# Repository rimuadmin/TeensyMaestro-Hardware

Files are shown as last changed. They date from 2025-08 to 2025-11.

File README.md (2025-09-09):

# TeensyMaestro Front Panel and PCB

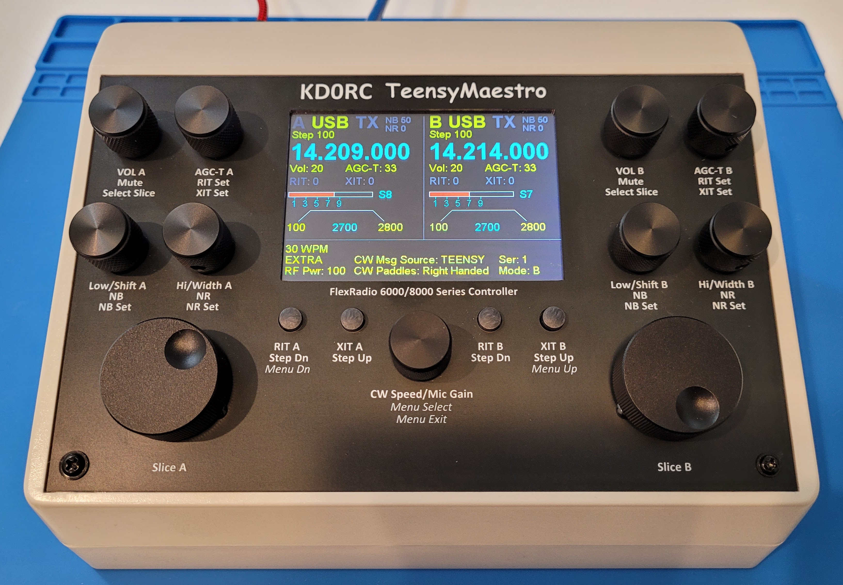
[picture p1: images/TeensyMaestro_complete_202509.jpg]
Assembled TeensyMaestro


### What Is TeensyMaestro?
The TeensyMaestro is a custom-built hardware controller first designed by Len (KD0RC) to interface with FlexRadio transceivers - specifically models in the 6000 and 8000 series. It performs some, but not all, of the common functions that the SmartSDR app or the Flex Maestro perform. The name TeensyMaestro comes from its core component: the Teensy 4.1 microcontroller, which powers the device. Len's initial version was built using point-to-point wiring which presented a challenge for builders. Len (KD0RC) and Simon (NV0E) have created a PCB and matching front panel that simplifies the build process. 

### What Is This Project?
This repository describes the version 2 PCB and Front Panel hardware. The intent of this PCB is to simplify the build process, make it easier to produce a polished final product, and replace some components with less expensive alternatives. It has detailed instructions that describe how to order parts, build and assemble a TeensyMaestro using the version 2 hardware.

The documentation for building the PCB and Front panel is here: 

[TeensyMaestro Hardware Wiki](https://github.com/rimuadmin/TeensyMaestro-Hardware/wiki)

Len's firmware that supports all versions is available here:

[TeensyMaestro for Flex 6000 Radios](https://github.com/KD0RC/Teensy-Maestro-for-Flex-6000-radios)

Len's GitHub page has a detailed user manual that explains how to operate the TeensyMaestro and build instructions for version 1.

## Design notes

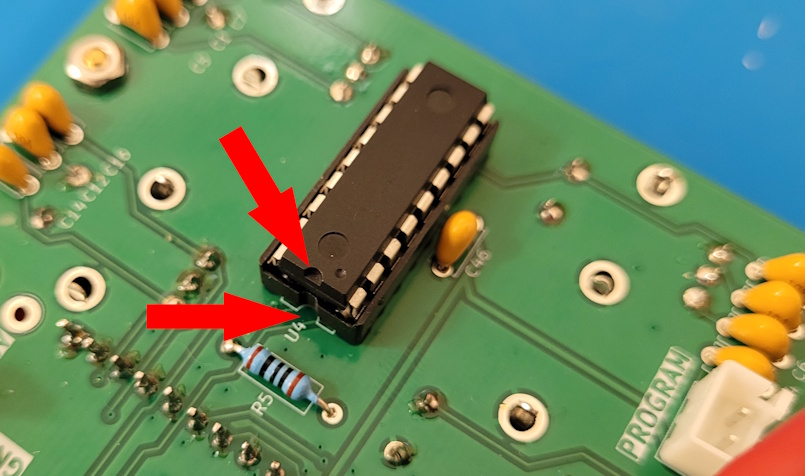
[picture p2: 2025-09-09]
images/mcp23008_right_position.jpg

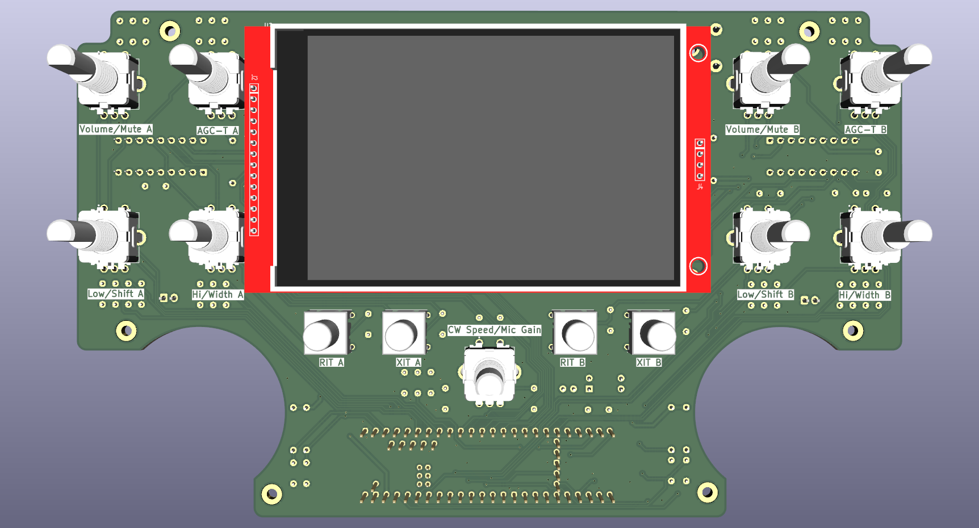
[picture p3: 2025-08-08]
images/front_side_2025-08-06.png

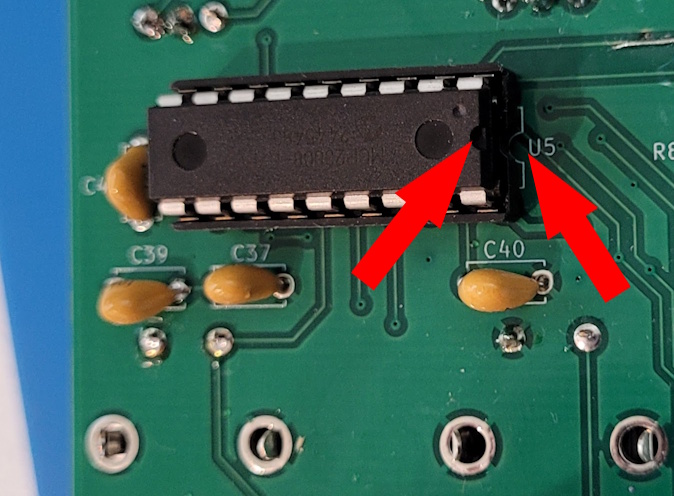
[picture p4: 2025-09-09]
images/mcp23008_left_position.jpg

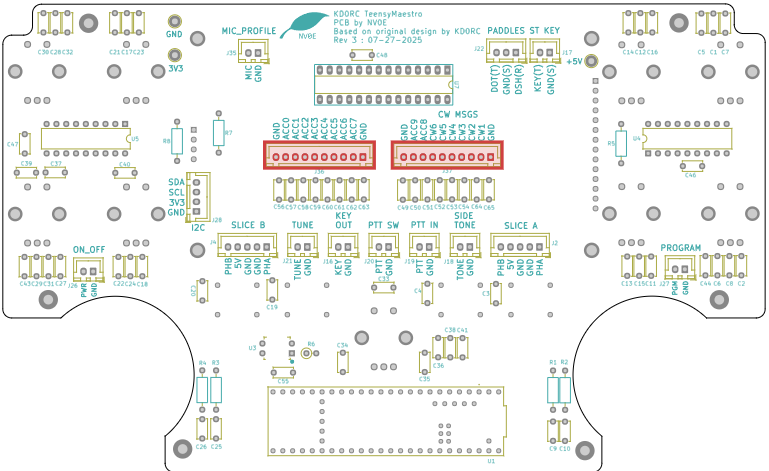
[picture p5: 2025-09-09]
images/XH_10-pin_connector.png

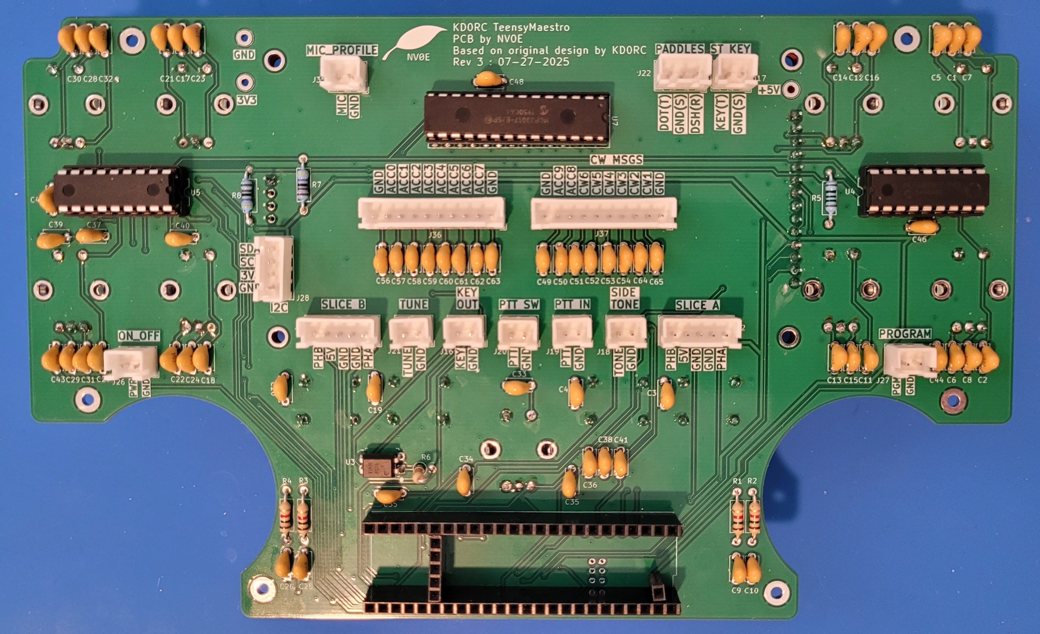
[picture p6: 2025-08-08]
images/TeensyMaestro_pcb_rear_20250806.jpg

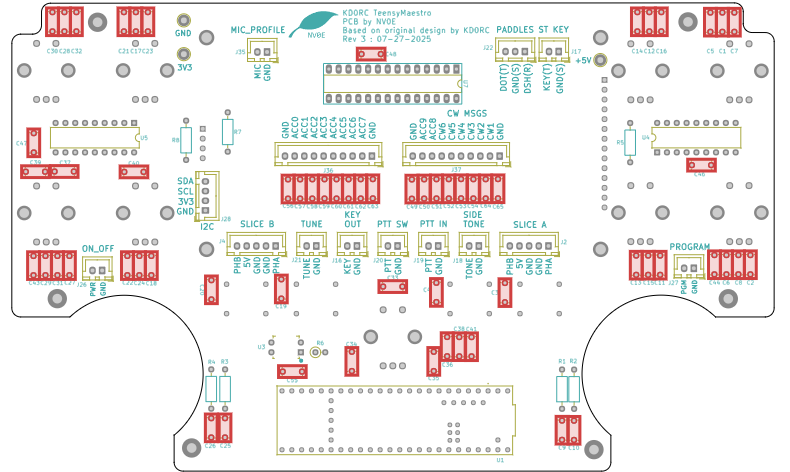
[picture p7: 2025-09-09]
images/tm_capacitor_positions.png

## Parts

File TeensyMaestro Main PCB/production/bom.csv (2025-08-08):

Designator | Footprint | Quantity | Value | LCSC Part #
C1, C10, C11, C12, C13, C14, C15, C16, C17, C18, C19, C2, C20, C21, C22, C23, C24, C25, C26, C27, C28, C29, C3, C30, C31, C32, C33, C34, C35, C36, C37, C38, C39, C4, C40, C41, C43, C44, C46, C47, C48, C49, C5, C50, C51, C52, C53, C54, C55, C56, C57, C58, C59, C6, C60, C61, C62, C63, C64, C65, C7, C8, C9 | C_Disc_D5.0mm_W2.5mm_P5.00mm | 63 | 100nF
H1, H2, H3, H4, H5, H6 | MountingHole_2.5mm_Pad | 6 | MountingHole
J16, J17, J18, J19, J20, J21, J26, J27, J35 | JST_XH_B2B-XH-A_1x02_P2.50mm_Vertical | 9 | B2B-XH-A_LF__SN_ | B2B-XH-A(LF)(SN)
J2, J4 | JST_XH_B5B-XH-A_1x05_P2.50mm_Vertical | 2 | B5B-XH-A_LF__SN_ | B5B-XH-A(LF)(SN)
J22 | JST_XH_B3B-XH-A_1x03_P2.50mm_Vertical | 1 | B3B-XH-A_LF__SN_ | B3B-XH-A(LF)(SN)
J28 | JST_XH_B4B-XH-A_1x04_P2.50mm_Vertical | 1 | B4B-PH-K-S_LF__SN_ | B4B-PH-K-S(LF)(SN)
J36, J37 | JST_XH_B10B-XH-A_1x10_P2.50mm_Vertical | 2 | Conn_01x10
R1, R2, R3, R4 | R_Axial_DIN0207_L6.3mm_D2.5mm_P10.16mm_Horizontal | 4 | 1K
R5 | R_Axial_DIN0207_L6.3mm_D2.5mm_P10.16mm_Horizontal | 1 | 100
R6 | R_Axial_DIN0207_L6.3mm_D2.5mm_P2.54mm_Vertical | 1 | 1K
R7, R8 | R_Axial_DIN0207_L6.3mm_D2.5mm_P10.16mm_Horizontal | 2 | 4K7
S1, S2, S3, S4 | 3ETH9120 | 4 | 1825910-6 | 1825910-6
SW10 | PEC11L4115FS0020_NR | 1 | AGC-T/RIT_Sel A
SW11 | PEC11L4115FS0020 | 1 | CW_Mic/Menu Sel
SW2 | PEC11L4115FS0020_NR | 1 | RotaryEncoder_Switch_MP
SW3 | PEC11L4115FS0020_NR | 1 | LowShift/NB A
SW4 | PEC11L4115FS0020_VNR | 1 | HighWidth/NR A
SW5 | PEC11L4115FS0020_VNR | 1 | AGC-T/RIT_Sel A
SW7 | PEC11L4115FS0020_VNR | 1 | Vol/Mute B
SW8 | PEC11L4115FS0020_VNR | 1 | LowShift/NB B
SW9 | PEC11L4115FS0020_NR | 1 | HighWidth/NR B
TP1 | TestPoint_Loop_D2.54mm_Drill1.5mm_Beaded | 1 | 5V
TP2 | TestPoint_Loop_D2.54mm_Drill1.5mm_Beaded | 1 | 3V3
TP3 | TestPoint_Loop_D2.54mm_Drill1.5mm_Beaded | 1 | GND
U1 | MODULE_DEV-16771 | 1 | DEV-16771
U2 | MSP4021-ST7796S-TM | 1 | MSP4021-ST7796S
U3 | DIP-4_W7.62mm | 1 | LTV-817 | LTV-817
U4, U5 | DIP-18_W7.62mm | 2 | MCP23008-xP
U7 | DIP-28_W7.62mm_Socket_LongPads | 1 | MCP23017-E_SP | MCP23017-E/SP

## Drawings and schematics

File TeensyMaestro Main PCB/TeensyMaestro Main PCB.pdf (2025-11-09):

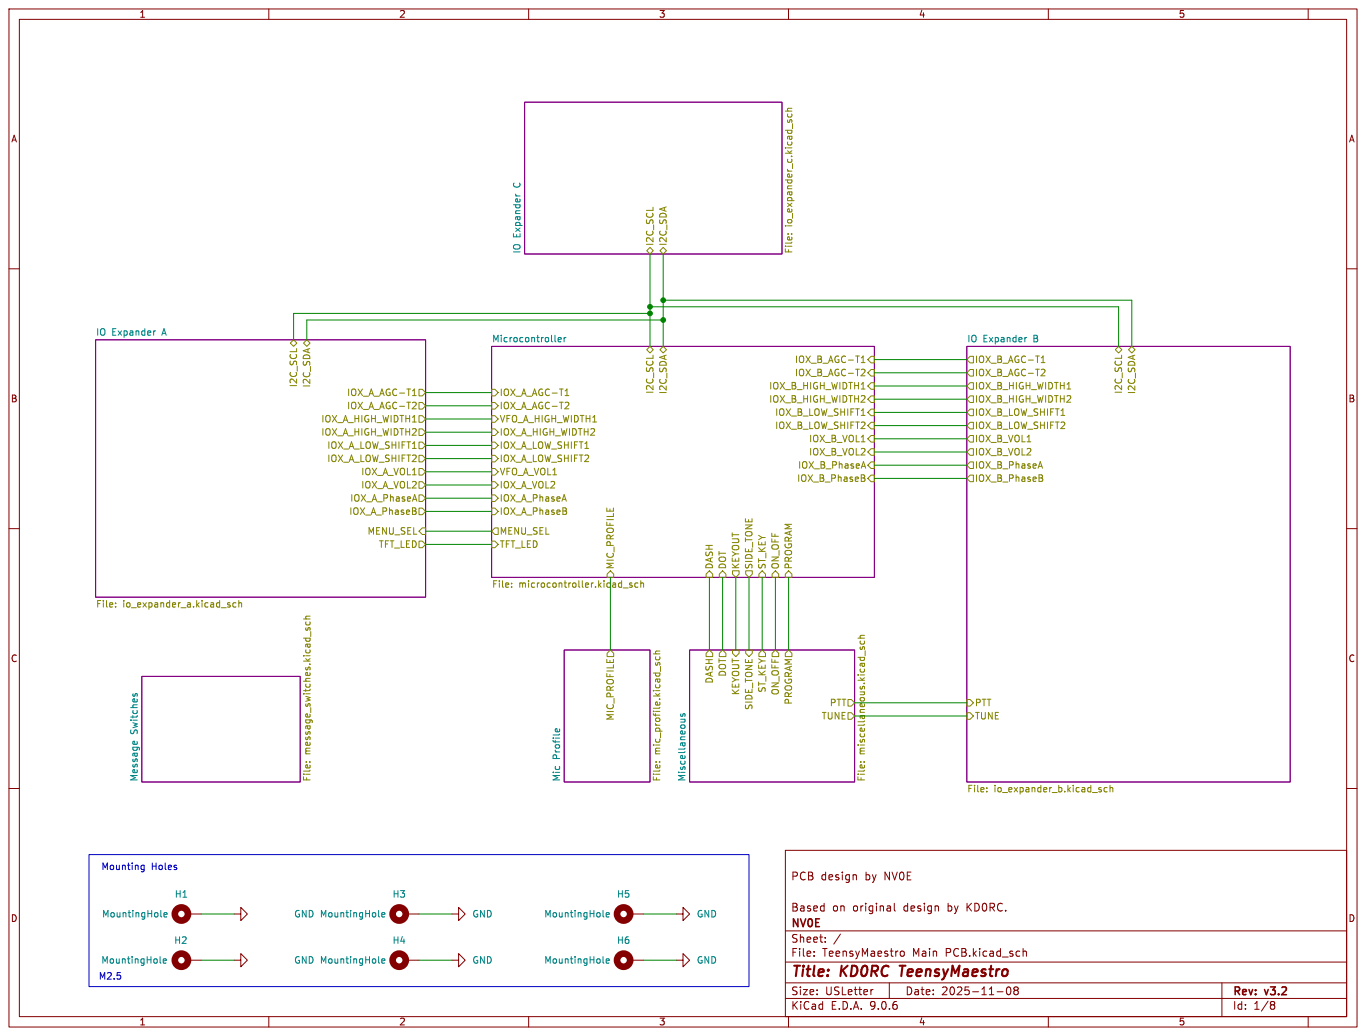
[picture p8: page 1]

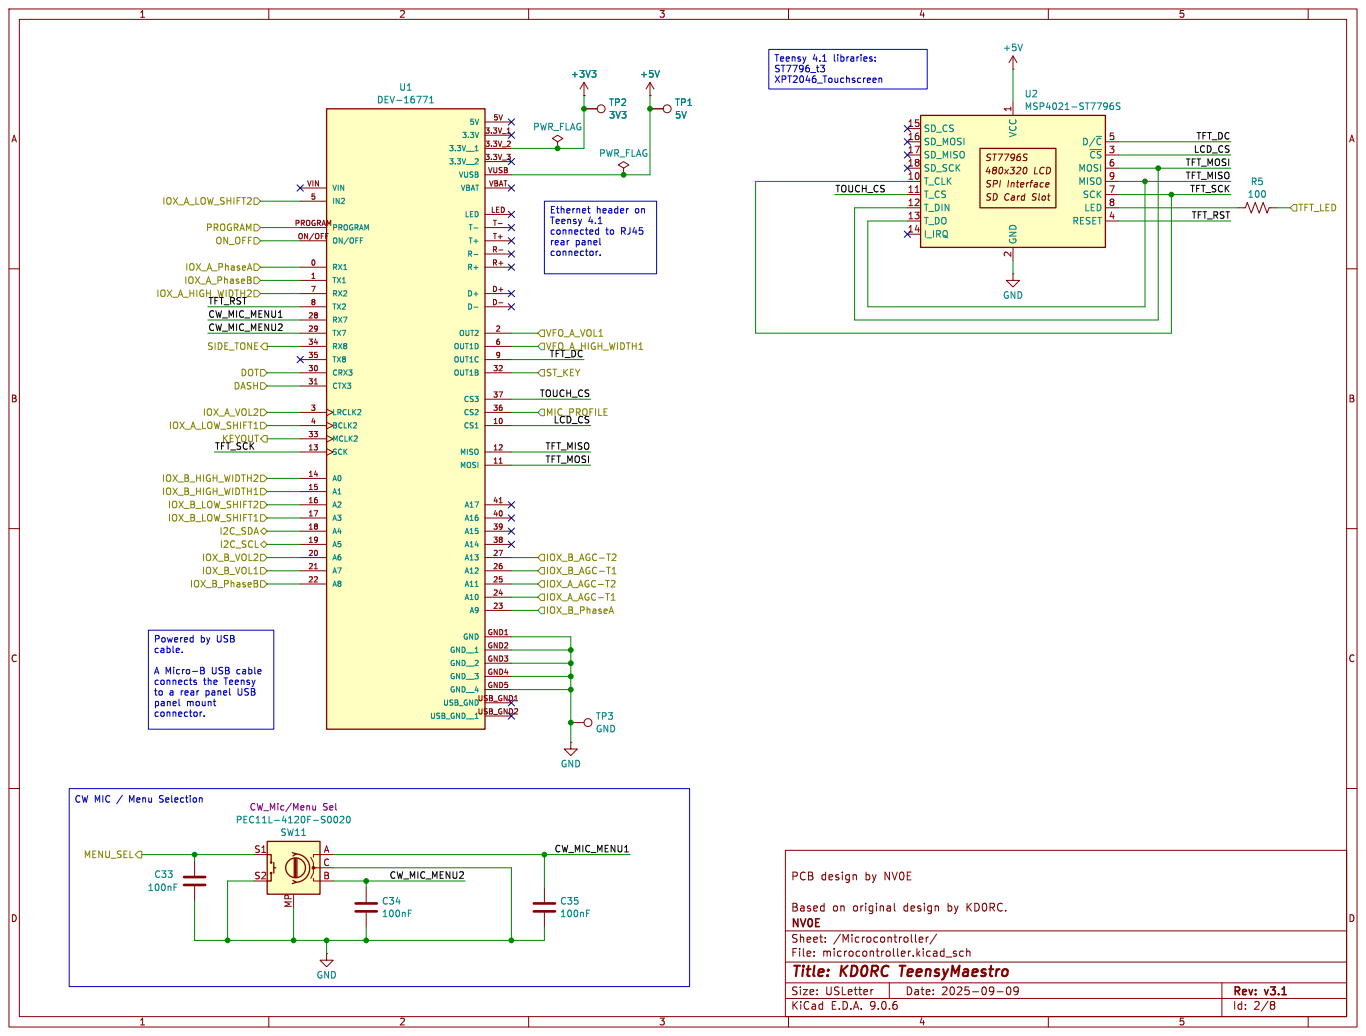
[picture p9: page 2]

Teensy 4.1 libraries: ST7796_t3 XPT2046_Touchscreen Powered by USB

2 D/~{C}5 ~{CS}3 MOSI 6 MISO 9 SCK 7

100 MIC_PROFILE
Ethernet header on Teensy 4.1

rear panel connector. CW MIC / Menu Selection

to a rear panel USB
panel mount connector.

File: microcontroller.kicad_sch Sheet: /Microcontroller/ NV0E

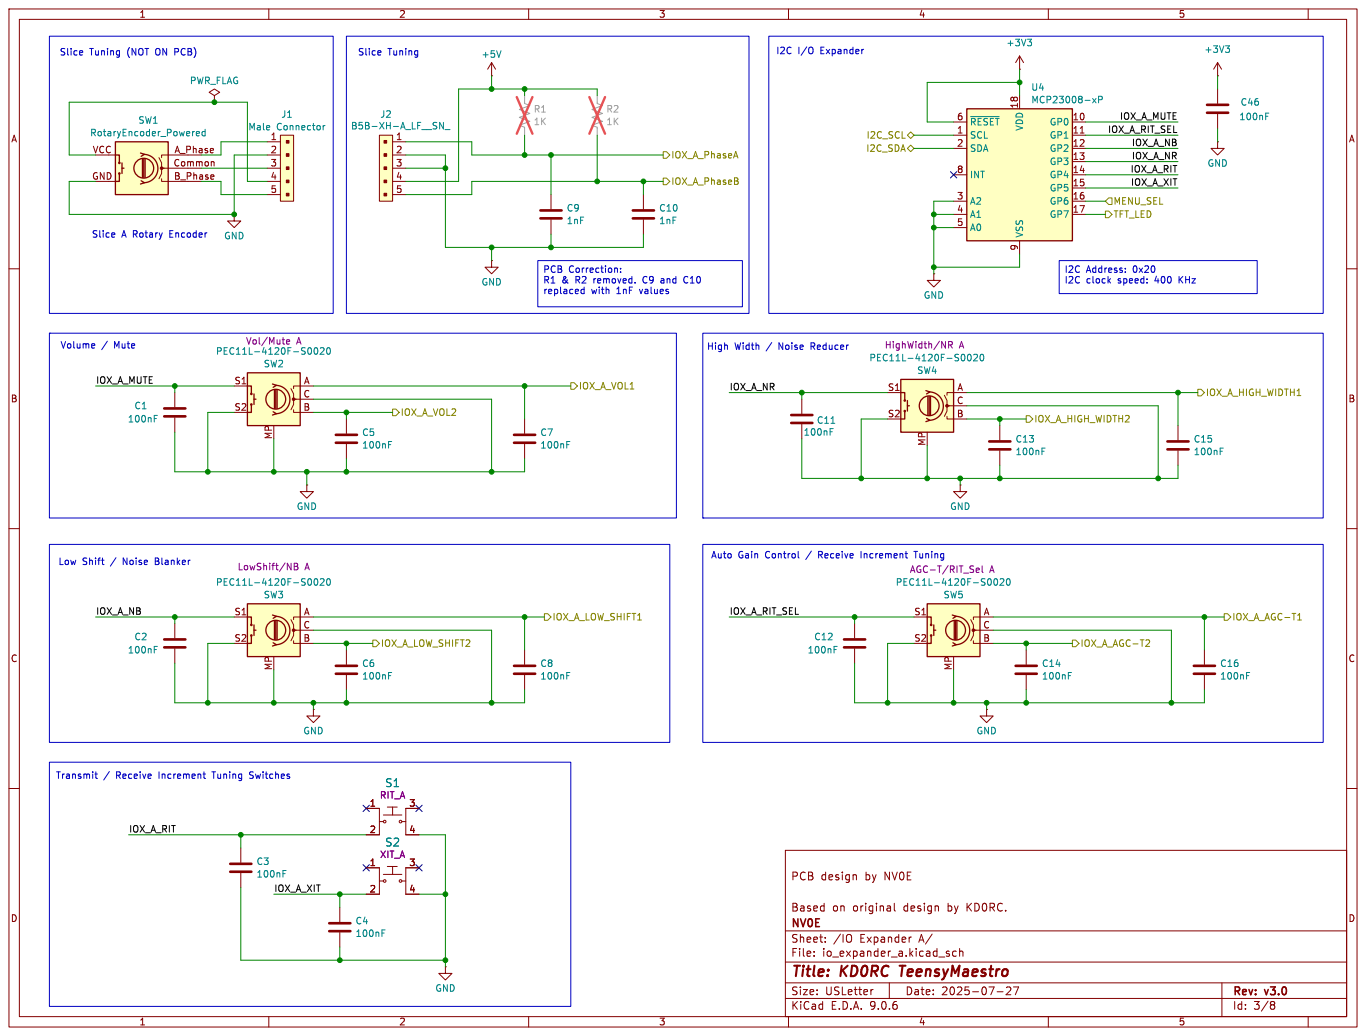
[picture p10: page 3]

I2C clock speed: 400 KHz PCB Correction: R1 & R2 removed. C9 and C10

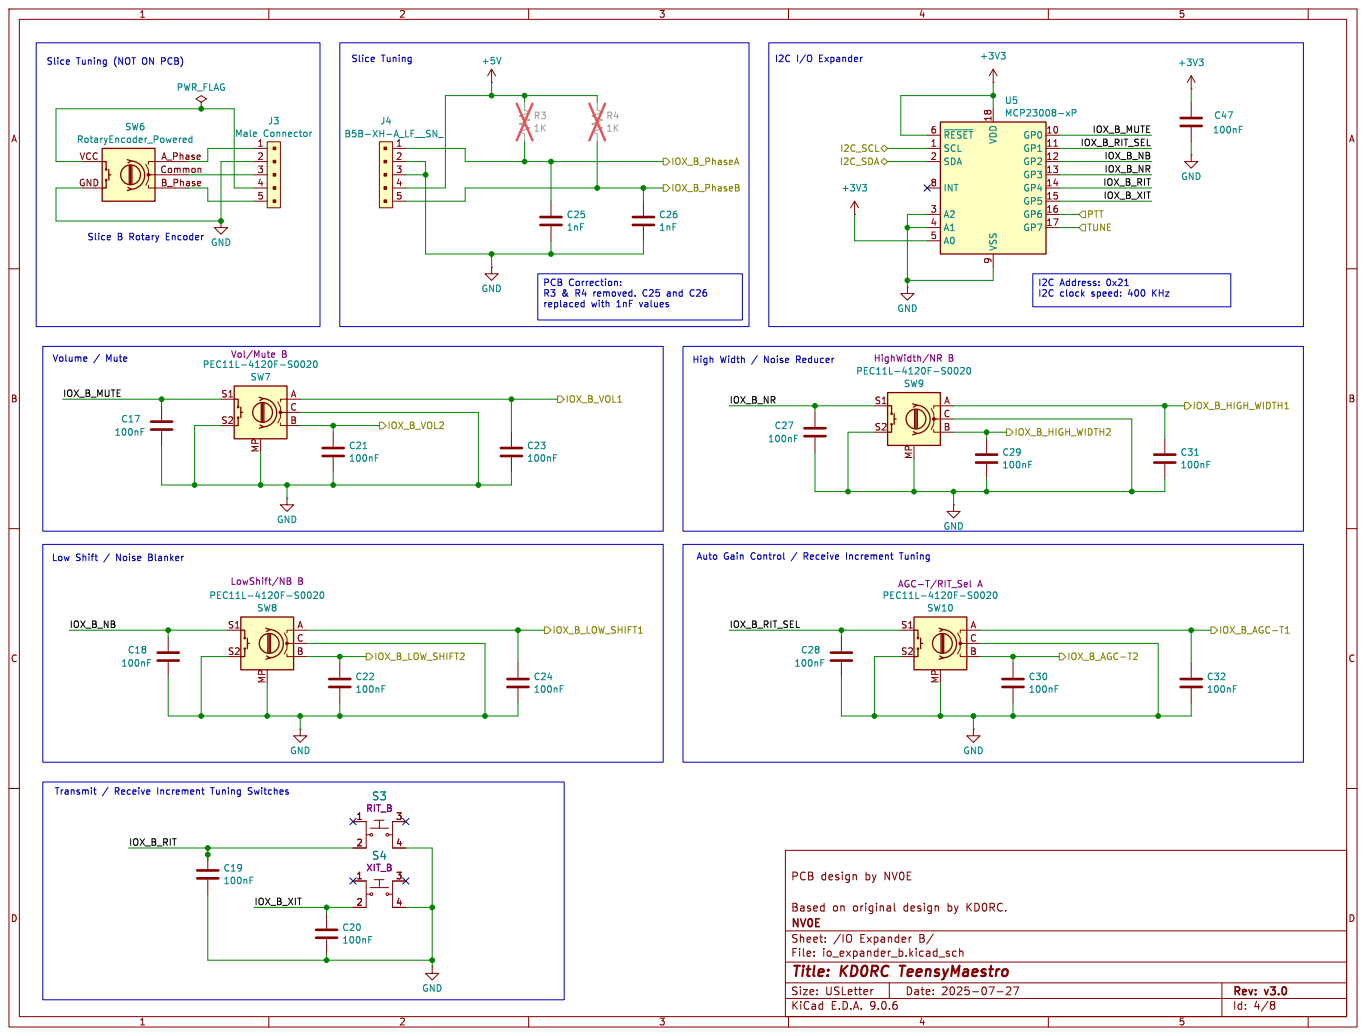
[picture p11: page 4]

I2C clock speed: 400 KHz PCB Correction: R3 & R4 removed. C25 and C26

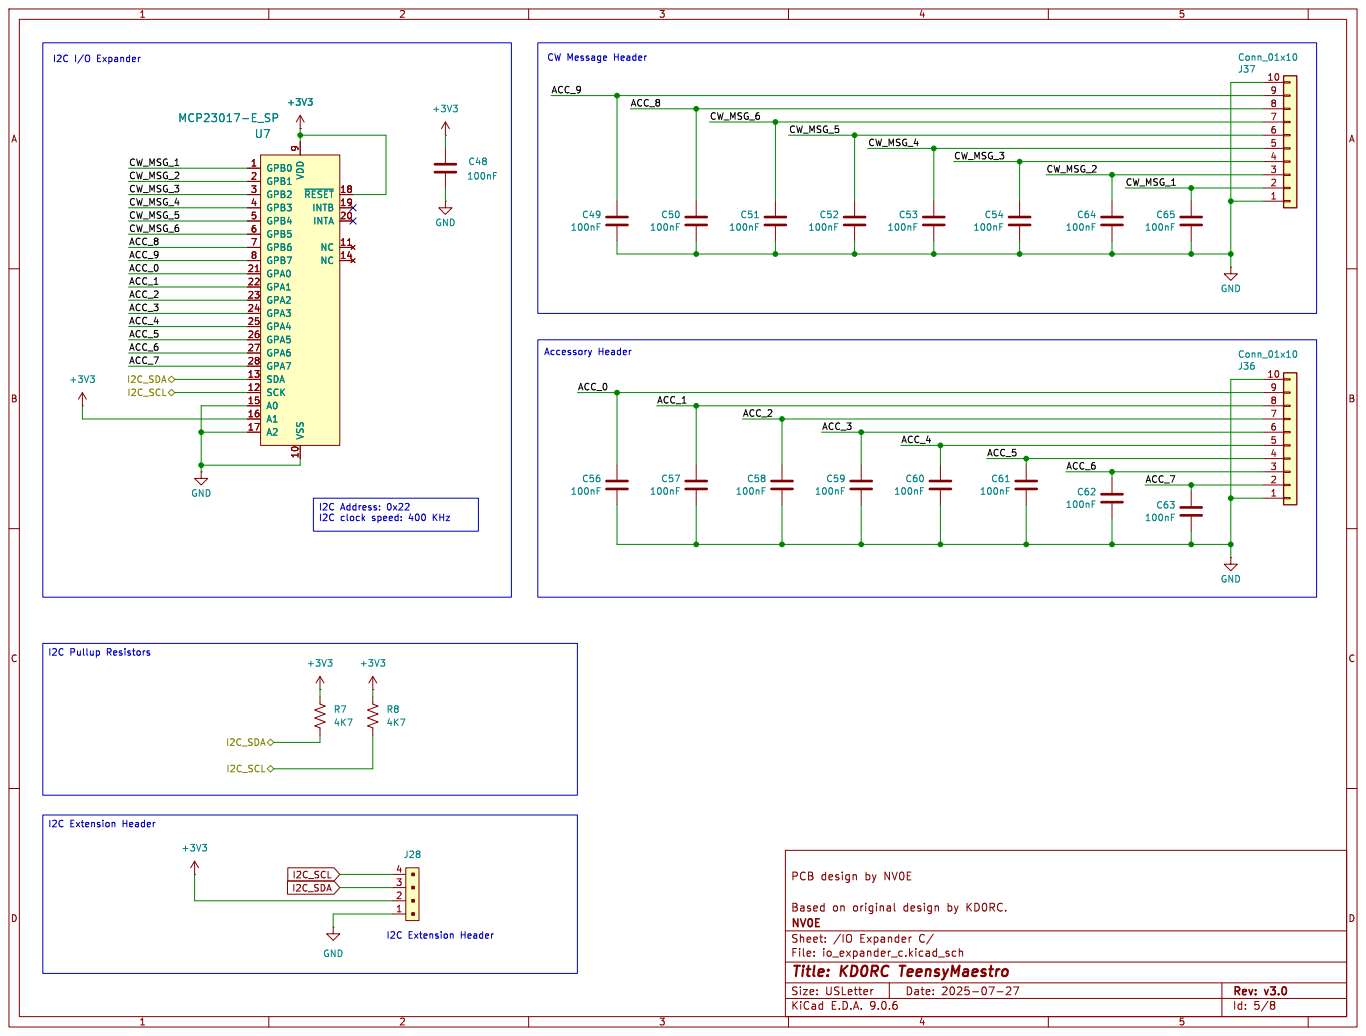
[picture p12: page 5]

Accessory Header CW Message Header U7 MCP23017-E_SP

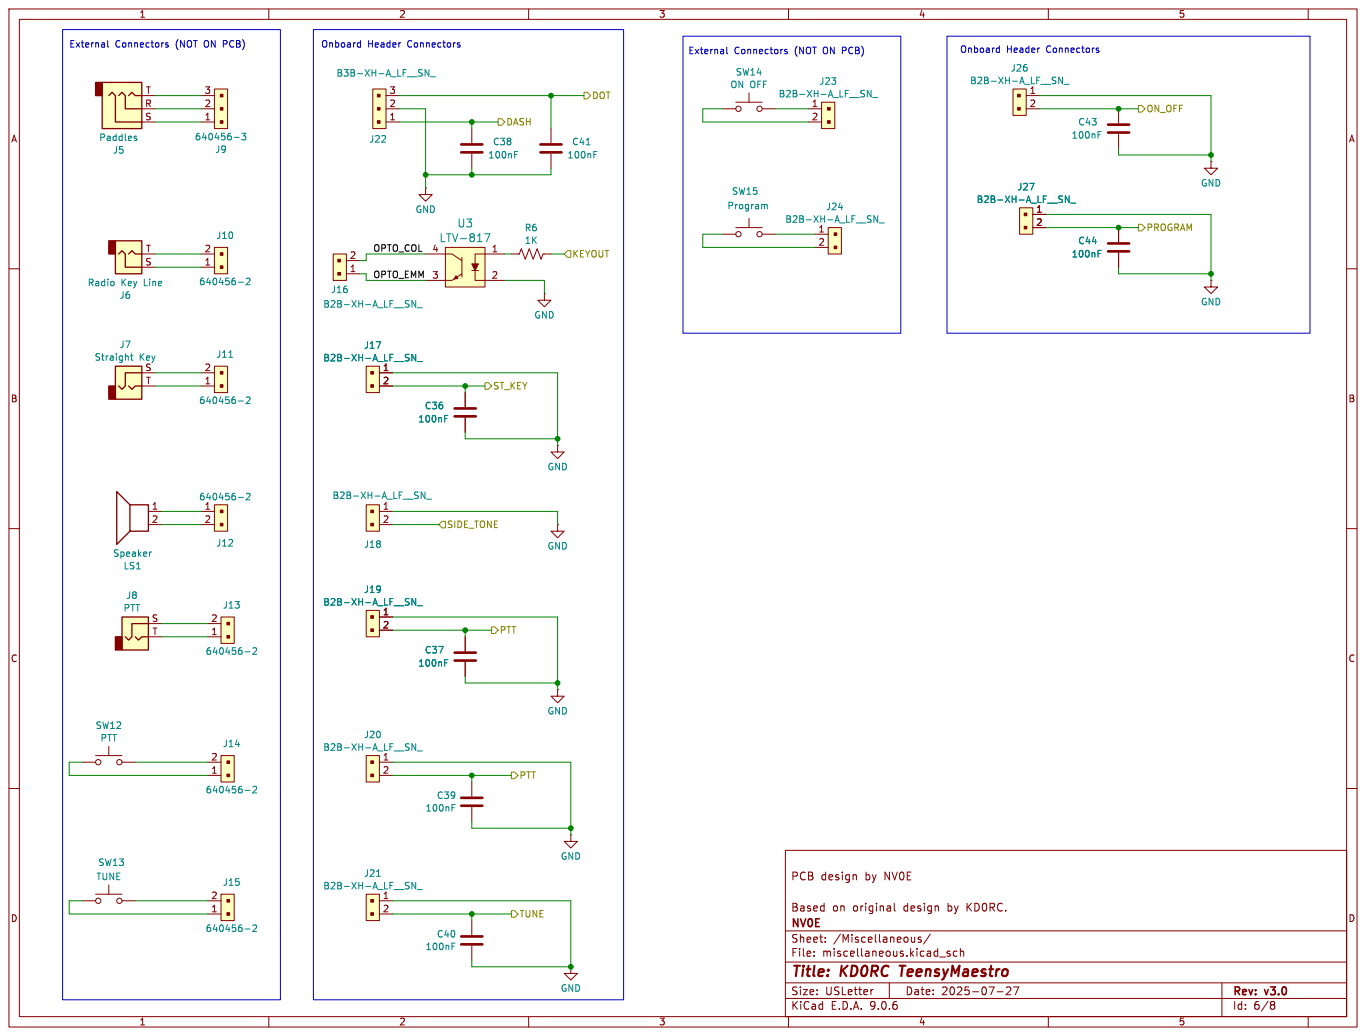
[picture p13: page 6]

J23 B2B-XH-A_LF__SN_ SW14 ON OFF SW15 Program

File: miscellaneous.kicad_sch Sheet: /Miscellaneous/ NV0E

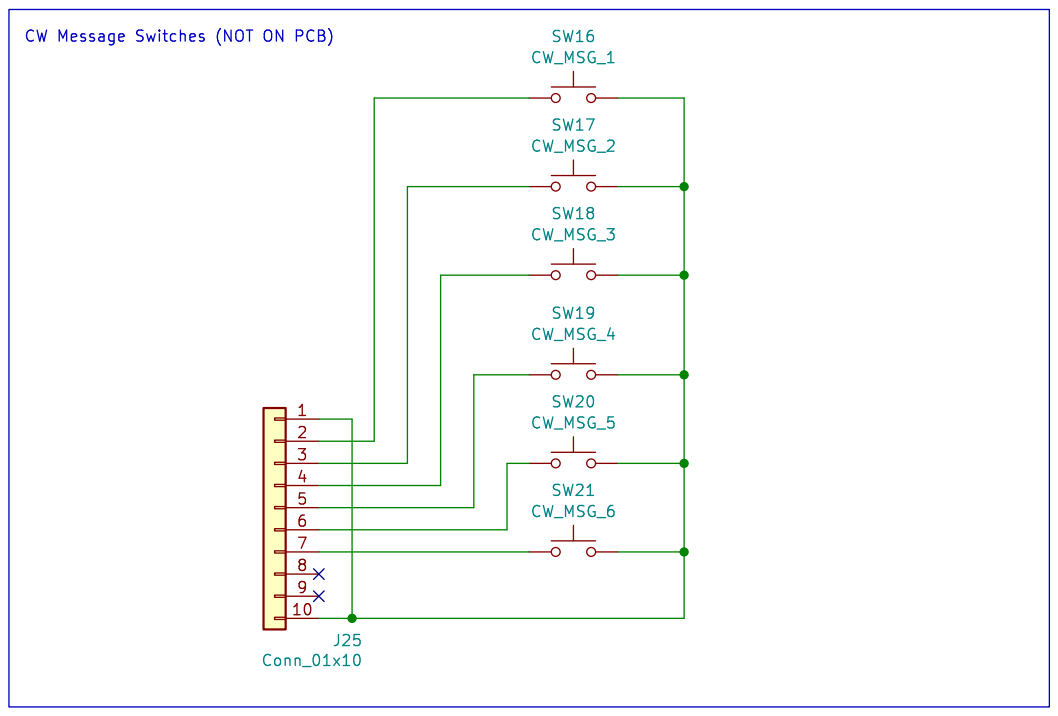
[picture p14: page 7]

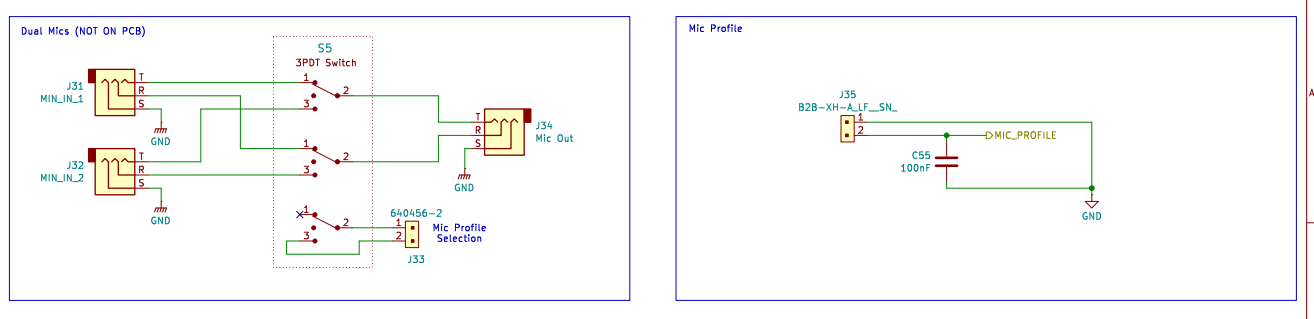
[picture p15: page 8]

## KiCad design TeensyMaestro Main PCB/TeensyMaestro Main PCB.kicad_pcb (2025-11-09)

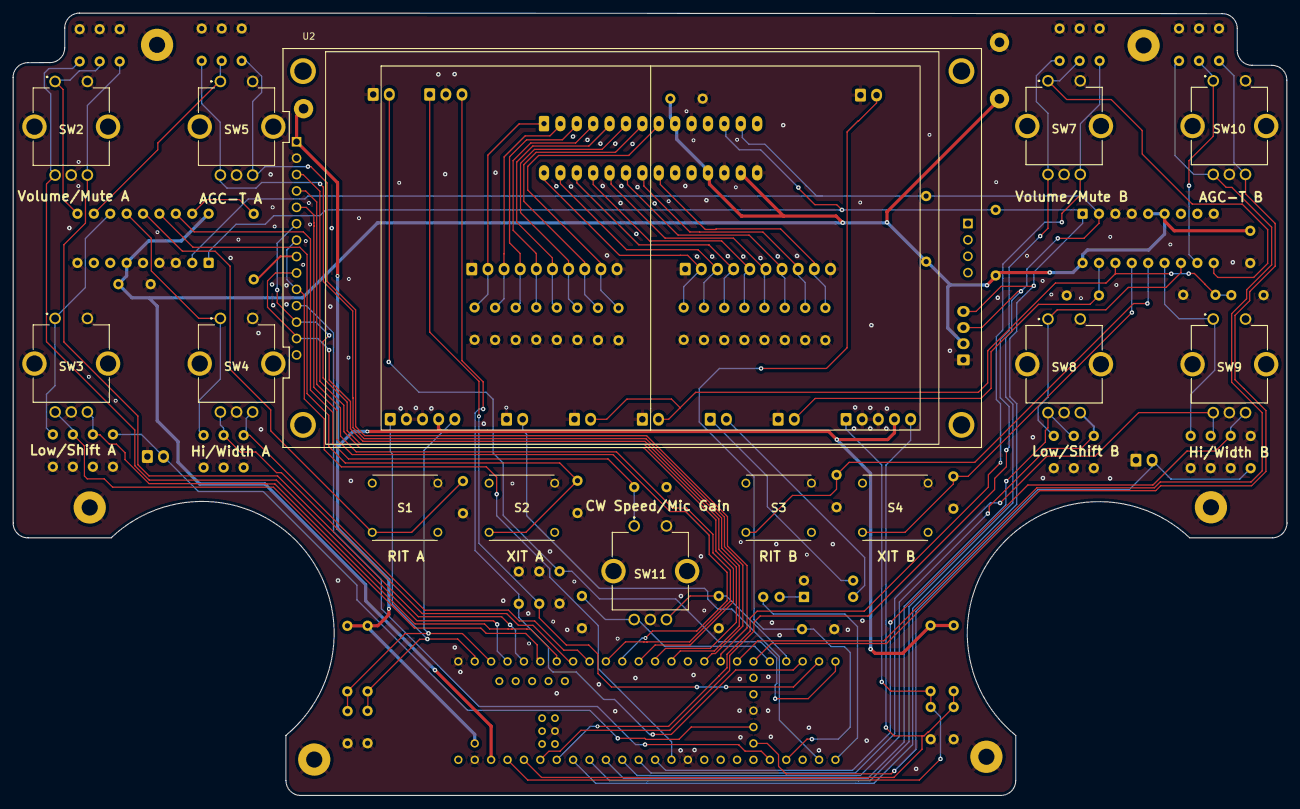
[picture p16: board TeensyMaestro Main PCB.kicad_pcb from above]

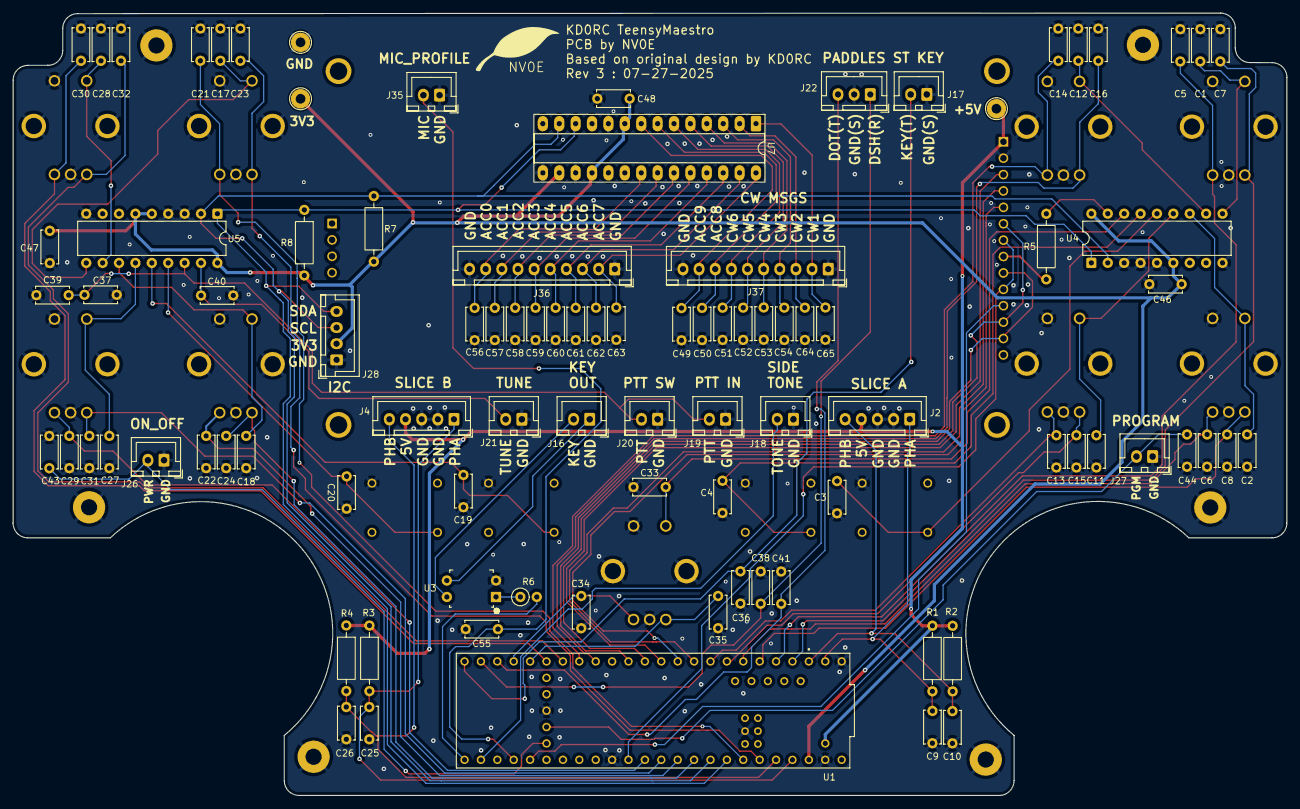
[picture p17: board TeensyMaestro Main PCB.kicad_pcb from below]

Board: 2 copper layers, 197.3 x 121.2 mm, 114 parts (94 on the bottom side), 78 nets.

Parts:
C1, C2, C3, C4, C5, C6, C7, C8, C11, C12, C13, C14, C15, C16, C17, C18, C19, C20, C21, C22, C23, C24, C27, C28, C29, C30, C31, C32, C33, C34, C35, C36, C37, C38, C39, C40, C41, C43, C44, C46, C47, C48, C49, C50, C51, C52, C53, C54, C55, C56, C57, C58, C59, C60, C61, C62, C63, C64, C65: 100nF; C_Disc_D5.0mm_W2.5mm_P5.00mm
C9, C10, C25, C26: 1nF; C_Disc_D5.0mm_W2.5mm_P5.00mm
H1, H2, H3, H4, H5, H6: MountingHole; MountingHole_2.5mm_Pad
J2, J4: B5B-XH-A_LF__SN_; JST_XH_B5B-XH-A_1x05_P2.50mm_Vertical
J16, J17, J18, J19, J20, J21, J26, J27, J35: B2B-XH-A_LF__SN_; JST_XH_B2B-XH-A_1x02_P2.50mm_Vertical
J22: B3B-XH-A_LF__SN_; JST_XH_B3B-XH-A_1x03_P2.50mm_Vertical
J28: B4B-PH-K-S_LF__SN_; JST_XH_B4B-XH-A_1x04_P2.50mm_Vertical
J36, J37: Conn_01x10; JST_XH_B10B-XH-A_1x10_P2.50mm_Vertical
R1, R2, R3, R4: 1K; R_Axial_DIN0207_L6.3mm_D2.5mm_P10.16mm_Horizontal
R5: 100; R_Axial_DIN0207_L6.3mm_D2.5mm_P10.16mm_Horizontal
R6: 1K; R_Axial_DIN0207_L6.3mm_D2.5mm_P2.54mm_Vertical
R7, R8: 4K7; R_Axial_DIN0207_L6.3mm_D2.5mm_P10.16mm_Horizontal
S1, S2, S3, S4: 1825910-6; 3ETH9120
SW2, SW3, SW9, SW10: PEC11L-4120F-S0020; PEC11L4115FS0020_NR
SW4, SW5, SW7, SW8: PEC11L-4120F-S0020; PEC11L4115FS0020_VNR
SW11: PEC11L-4120F-S0020; PEC11L4115FS0020
TP1: 5V; TestPoint_Loop_D2.54mm_Drill1.5mm_Beaded
TP2: 3V3; TestPoint_Loop_D2.54mm_Drill1.5mm_Beaded
TP3: GND; TestPoint_Loop_D2.54mm_Drill1.5mm_Beaded
U1: DEV-16771; MODULE_DEV-16771
U2: MSP4021-ST7796S; MSP4021-ST7796S-TM
U3: LTV-817; DIP-4_W7.62mm
U4, U5: MCP23008-xP; DIP-18_W7.62mm
U7: MCP23017-E_SP; DIP-28_W7.62mm_Socket_LongPads

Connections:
+3V3: C46.1, C47.1, C48.1, J28.2, R7.2, R8.2, TP2.1, U1.3.3V_2 (3.3V__1), U4.6 (~RESET), U4.18 (VDD), U5.5 (A0), U5.6 (~RESET), U5.18 (VDD), U7.9 (VDD), U7.16 (A1), U7.18 (~RESET)
+5V: J2.4, J4.4, R1.1, R2.1, R3.1, R4.1, TP1.1, U1.VUSB, U2.1 (VCC)
/IO Expander A/IOX_A_AGC-T1: C16.1, SW5.A, U1.24 (A10)
/IO Expander A/IOX_A_AGC-T2: C14.1, SW5.B, U1.25 (A11)
/IO Expander A/IOX_A_HIGH_WIDTH1: C15.1, SW4.A, U1.6 (OUT1D)
/IO Expander A/IOX_A_HIGH_WIDTH2: C13.1, SW4.B, U1.7 (RX2)
/IO Expander A/IOX_A_LOW_SHIFT1: C8.1, SW3.A, U1.4 (BCLK2)
/IO Expander A/IOX_A_LOW_SHIFT2: C6.1, SW3.B, U1.5 (IN2)
/IO Expander A/IOX_A_MUTE: C1.1, SW2.S1, U4.10 (GP0)
/IO Expander A/IOX_A_NB: C2.1, SW3.S1, U4.12 (GP2)
/IO Expander A/IOX_A_NR: C11.1, SW4.S1, U4.13 (GP3)
/IO Expander A/IOX_A_PhaseA: C9.1, J2.1, R1.2, U1.0 (RX1)
/IO Expander A/IOX_A_PhaseB: C10.1, J2.5, R2.2, U1.1 (TX1)
/IO Expander A/IOX_A_RIT: C3.1, S1.2, U4.14 (GP4)
/IO Expander A/IOX_A_RIT_SEL: C12.1, SW5.S1, U4.11 (GP1)
/IO Expander A/IOX_A_VOL1: C7.1, SW2.A, U1.2 (OUT2)
/IO Expander A/IOX_A_VOL2: C5.1, SW2.B, U1.3 (LRCLK2)
/IO Expander A/IOX_A_XIT: C4.1, S2.2, U4.15 (GP5)
/IO Expander A/MENU_SEL: C33.1, SW11.S1, U4.16 (GP6)
/IO Expander A/TFT_LED: R5.2, U4.17 (GP7)
/IO Expander B/IOX_B_AGC-T1: C32.1, SW10.A, U1.26 (A12)
/IO Expander B/IOX_B_AGC-T2: C30.1, SW10.B, U1.27 (A13)
/IO Expander B/IOX_B_HIGH_WIDTH1: C31.1, SW9.A, U1.15 (A1)
/IO Expander B/IOX_B_HIGH_WIDTH2: C29.1, SW9.B, U1.14 (A0)
/IO Expander B/IOX_B_LOW_SHIFT1: C24.1, SW8.A, U1.17 (A3)
/IO Expander B/IOX_B_LOW_SHIFT2: C22.1, SW8.B, U1.16 (A2)
/IO Expander B/IOX_B_MUTE: C17.1, SW7.S1, U5.10 (GP0)
/IO Expander B/IOX_B_NB: C18.1, SW8.S1, U5.12 (GP2)
/IO Expander B/IOX_B_NR: C27.1, SW9.S1, U5.13 (GP3)
/IO Expander B/IOX_B_PhaseA: C25.1, J4.1, R3.2, U1.23 (A9)
/IO Expander B/IOX_B_PhaseB: C26.1, J4.5, R4.2, U1.22 (A8)
/IO Expander B/IOX_B_RIT: C19.1, S3.2, U5.14 (GP4)
/IO Expander B/IOX_B_RIT_SEL: C28.1, SW10.S1, U5.11 (GP1)
/IO Expander B/IOX_B_VOL1: C23.1, SW7.A, U1.21 (A7)
/IO Expander B/IOX_B_VOL2: C21.1, SW7.B, U1.20 (A6)
/IO Expander B/IOX_B_XIT: C20.1, S4.2, U5.15 (GP5)
/IO Expander B/PTT: C37.1, C39.1, J19.2, J20.2, U5.16 (GP6)
/IO Expander B/TUNE: C40.1, J21.2, U5.17 (GP7)
/IO Expander C/ACC_0: C56.1, J36.9, U7.21 (GPA0)
/IO Expander C/ACC_1: C57.1, J36.8, U7.22 (GPA1)
/IO Expander C/ACC_2: C58.1, J36.7, U7.23 (GPA2)
/IO Expander C/ACC_3: C59.1, J36.6, U7.24 (GPA3)
/IO Expander C/ACC_4: C60.1, J36.5, U7.25 (GPA4)
/IO Expander C/ACC_5: C61.1, J36.4, U7.26 (GPA5)
/IO Expander C/ACC_6: C62.1, J36.3, U7.27 (GPA6)
/IO Expander C/ACC_7: C63.1, J36.2, U7.28 (GPA7)
/IO Expander C/ACC_8: C50.1, J37.8, U7.7 (GPB6)
/IO Expander C/ACC_9: C49.1, J37.9, U7.8 (GPB7)
/IO Expander C/CW_MSG_1: C65.1, J37.2, U7.1 (GPB0)
/IO Expander C/CW_MSG_2: C64.1, J37.3, U7.2 (GPB1)
/IO Expander C/CW_MSG_3: C54.1, J37.4, U7.3 (GPB2)
/IO Expander C/CW_MSG_4: C53.1, J37.5, U7.4 (GPB3)
/IO Expander C/CW_MSG_5: C52.1, J37.6, U7.5 (GPB4)
/IO Expander C/CW_MSG_6: C51.1, J37.7, U7.6 (GPB5)
/Mic Profile/MIC_PROFILE: C55.1, J35.2, U1.36 (CS2)
/Microcontroller/CW_MIC_MENU1: C35.1, SW11.A, U1.28 (RX7)
/Microcontroller/CW_MIC_MENU2: C34.1, SW11.B, U1.29 (TX7)
/Microcontroller/DASH: C38.1, J22.1, U1.31 (CTX3)
/Microcontroller/DOT: C41.1, J22.3, U1.30 (CRX3)
/Microcontroller/KEYOUT: R6.2, U1.33 (MCLK2)
/Microcontroller/LCD_CS: U1.10 (CS1), U2.3 (~CS)
/Microcontroller/ON_OFF: C43.1, J26.2, U1.ON/OFF
/Microcontroller/PROGRAM: C44.1, J27.2, U1.PROGRAM
/Microcontroller/SIDE_TONE: J18.2, U1.34 (RX8)
/Microcontroller/ST_KEY: C36.1, J17.2, U1.32 (OUT1B)
/Microcontroller/TFT_DC: U1.9 (OUT1C), U2.5 (D/~C)
/Microcontroller/TFT_MISO: U1.12 (MISO), U2.9 (MISO), U2.13 (T_DO)
/Microcontroller/TFT_MOSI: U1.11 (MOSI), U2.6 (MOSI), U2.12 (T_DIN)
/Microcontroller/TFT_RST: U1.8 (TX2), U2.4 (RESET)
/Microcontroller/TFT_SCK: U1.13 (SCK), U2.7 (SCK), U2.10 (T_CLK)
/Microcontroller/TOUCH_CS: U1.37 (CS3), U2.11 (T_CS)
/Miscellaneous/OPTO_COL: J16.2, U3.4
/Miscellaneous/OPTO_EMM: J16.1, U3.3
GND: C1.2, C2.2, C3.2, C4.2, C5.2, C6.2, C7.2, C8.2, C9.2, C10.2, C11.2, C12.2, C13.2, C14.2, C15.2, C16.2, C17.2, C18.2, C19.2, C20.2, C21.2, C22.2, C23.2, C24.2, C25.2, C26.2, C27.2, C28.2, C29.2, C30.2, C31.2, C32.2, C33.2, C34.2, C35.2, C36.2, C37.2, C38.2, C39.2, C40.2, C41.2, C43.2, C44.2, C46.2, C47.2, C48.2, C49.2, C50.2, C51.2, C52.2, C53.2, C54.2, C55.2, C56.2, C57.2, C58.2, C59.2, C60.2, C61.2, C62.2, C63.2, C64.2, C65.2, H1.1, H2.1, H3.1, H4.1, H5.1, H6.1, J2.2, J2.3, J4.2, J4.3, J17.1, J18.1, J19.1, J20.1, J21.1, J22.2, J26.1, J27.1, J28.1, J35.1, J36.1, J36.10, J37.1, J37.10, S1.4, S2.4, S3.4, S4.4, SW2.C, SW2.MP, SW2.S2, SW3.C, SW3.MP, SW3.S2, SW4.C, SW4.MP, SW4.S2, SW5.C, SW5.MP, SW5.S2, SW7.C, SW7.MP, SW7.S2, SW8.C, SW8.MP, SW8.S2, SW9.C, SW9.MP, SW9.S2, SW10.C, SW10.MP, SW10.S2, SW11.C, SW11.MP, SW11.S2, TP3.1, U1.GND1 (GND), U1.GND2 (GND__1), U1.GND3 (GND__2), U1.GND4 (GND__3), U1.GND5 (GND__4), U2.2 (GND), U3.2, U4.3 (A2), U4.4 (A1), U4.5 (A0), U4.9 (VSS), U5.3 (A2), U5.4 (A1), U5.9 (VSS), U7.10 (VSS), U7.15 (A0), U7.17 (A2)
I2C_SCL: J28.4, R8.1, U1.19 (A5), U4.1 (SCL), U5.1 (SCL), U7.12 (SCK)
I2C_SDA: J28.3, R7.1, U1.18 (A4), U4.2 (SDA), U5.2 (SDA), U7.13 (SDA)
unnamed: R6.1, U3.1
unnamed: R5.1, U2.8 (LED)

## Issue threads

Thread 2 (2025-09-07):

Docs, add optional microSD card to BOM and brief guidance

besynnerlig, 2025-09-07:
**Summary**
I suggest adding information about the optional microSD card for Teensy 4.1. There is currently no guidance, which makes builders guess about capacity, file system, and card class. A few lines of documentation would save time and reduce support questions. Also add the card as **optional** in the BOM.

**Proposed BOM entry, to be verified by maintainers**
Optional, microSD card, 16 to 32 GB, A1, UHS I, U1

## Why this matters
* TeensyMaestro reads small configuration files, for example `MMConfig.ini`, and possibly tiny memory files. The workload is small random I and O, not large sequential media recording.
* Without guidance, people buy very large or exotic cards, then hit formatting or library limitations that are easy to avoid.

## What I **guess** most builders need, to be verified by maintainers
* A small, reliable card, microSDHC 16 to 32 GB, **A1**, **UHS I**, **U1** might a safe choice. 64 GB might also work?
* Cards larger than 32 GB, for example 64 GB SDXC, usually ship as **exFAT**. That often works with recent Teensyduino and SdFat, however **FAT32** remains the least surprising option for sketches that only expect FAT.
* **A1** cards are optimized for small random reads and writes, which fits microcontroller use. **A2** can be slower on simple hosts if the driver stack does not use its advanced features.
* **UHS II** brings no benefit here, the Teensy 4.1 slot is a standard SDIO host.

**Questions for maintainers**
* Confirm recommended file system for the current build, exFAT or FAT32
* Any preferred allocation unit size for exFAT or FAT32
* Any tested maximum card size that you recommend

rimuadmin, 2025-09-07:
Thanks besynnerlig. I've added the MicroSD card to the BOM.

Closed 2025-09-07.

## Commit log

2025-08-30 Correct 8-pin to 10-pin
2025-09-09 Updated documentation in schematic
    [TeensyMaestro Main PCB.kicad_pcb, TeensyMaestro Main PCB.kicad_sch, io_expander_a.kicad_sch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]
2025-09-09 Regenerated schematic pdf
2025-11-09 Update schematic with 5v pullup correction
    [TeensyMaestro Main PCB.kicad_sch, io_expander_a.kicad_sch, io_expander_b.kicad_sch]
2025-11-09 Update schematic & BOM with 5v pullup correction
    [TeensyMaestro Main PCB.kicad_pcb, io_expander_b.kicad_sch]
